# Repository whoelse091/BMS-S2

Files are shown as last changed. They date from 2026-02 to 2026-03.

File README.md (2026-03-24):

# BMS-USB CHARGE 2S (Rev V1)
 
Плата управления и защиты (BMS) для сборок из двух последовательных Li-Ion аккумуляторов (2S). Рассчитана на длительную работу при токах до 7 А с пиковой нагрузкой до 10 А и пассивной балансировкой ячеек



---
 
## Характеристики
 
| Параметр | Значение |
| :--- | :--- |
| Конфигурация | 2S (7.4–8.4 В) |
| Номинальный ток нагрузки | 7 А |
| Пиковый ток | 10 А |
| Ток балансировки | 100 мА |
| Контроллер защиты | HY2120 |
| Контроллер балансировки | HY2213 |
 
---

## Схемотехника
 
Схема состоит из трёх функциональных блоков: защита сборки, балансировка ячейки 1 и балансировка ячейки 2. Аккумуляторы BT1 и BT2 соединены последовательно: PB+ → BT1 → B1+2 (средняя точка) → BT2 → GND.

 

### Защита сборки (Battery Protection)
 
Контроллер **U3 (HY2120)** отслеживает напряжение каждой ячейки и ток нагрузки, обеспечивая защиту от перезаряда, переразряда и короткого замыкания.



Входные цепи:
- Напряжение верхней ячейки (BT1) снимается между PB+ и B1+2 через резистивные цепи R2 (330 Ом) на вход VDD и RB (330 Ом) на вход VC.
- Конденсаторы C3 и C5 (по 0.1 мкФ) — блокировочные ёмкости по питанию и опорному входу.
 
Токовый датчик:
- Вход CS (pin 3) подключён через R9 (2 кОм) к средней точке между стоковыми выводами силовых MOSFET. Падение напряжения на открытых каналах Q3/Q4 используется как шунт для определения тока нагрузки.
 
Силовые ключи:
- **Q3** и **Q4** (AOD4184A) включены по схеме back-to-back (общий сток) в минусовую шину между GND сборки и GND1 нагрузки.
- Выход **OD** (pin 1) управляет затвором Q4 и отвечает за отключение при переразряде.
- Выход **OC** (pin 2) управляет затвором Q3 и отвечает за отключение при перезаряде/КЗ.
- R14 и R15 (по 100 кОм) — подтяжка затворов к GND для гарантированного закрытия MOSFET при обесточенном контроллере.
 
### Балансировка ячейки 1 (Balancing Battery 1)
 
Контроллер **U1 (HY2213)** контролирует напряжение на BT1 через входы VDD(B1) и VSS. Питание подведено через R1 (100 Ом) с блокировочным конденсатором C1 (0.1 мкФ).
 
При достижении порогового напряжения на ячейке (типовое ~4.25 В) выход **OUT1** (pin 6) через R16 (100 кОм) открывает MOSFET **Q1 (AOD4184A)**, который подключает балансировочную нагрузку — параллельную пару резисторов **R4 и R6** (по 90 Ом, суммарно 45 Ом). Ток балансировки при напряжении ячейки ~4.2 В составляет примерно **93 мА**.



### Балансировка ячейки 2 (Balancing Battery 2)
 
Схема полностью симметрична блоку балансировки ячейки 1.
 
Контроллер **U2 (HY2213)** контролирует напряжение на BT2. Питание — через R5 (100 Ом), блокировка — C4 (0.1 мкФ). Выход **OUT2** (pin 6) через R17 (100 кОм) управляет MOSFET **Q2 (AOD4184A)**, который коммутирует балансировочные резисторы **R3 и R7** (по 90 Ом, суммарно 45 Ом).
 
### Выходной разъём (Wire-Pad)
 
Выходные контакты:
- **J2** (Conn_01x01) — PB+ (положительный выход сборки).
- **J3** (Conn_01x01) — GND1 (отрицательный выход, после силовых ключей защиты).
 
---

## Конструктив платы
 
Двухслойная PCB, спроектированная под высокие токовые нагрузки.
 
- **Силовые трассы** — увеличенная ширина дорожек для минимизации падения напряжения и нагрева при пиковых 10 А.
- **Заливка медью (Copper Pour)** — сплошные полигоны GND на обоих слоях. Обеспечивают низкоимпедансную «землю» и улучшают помехоустойчивость аналоговых цепей HY2120/HY2213.
- **Монтаж аккумуляторов** — контактные площадки и крепления вынесены на нижний слой (Bottom), что разделяет силовую и сигнальную части.
- **Теплоотвод** — via stitching под силовыми компонентами и широкие медные полигоны для рассеивания тепла от балансировочных резисторов и MOSFET.
- **Форм-фактор** — компактный, рассчитан на прямую установку поверх аккумуляторной сборки.




## Структура проекта
* `/electronics` — Схемы (PDF) и исходники KiCad.
* `/gerber` — Файлы для производства печатных плат.
* `/docs` — Инструкции и фотографии тестов.

## Особенность первого запуска и выхода из защиты
 
После сборки платы или после срабатывания защиты (переразряд, КЗ) на выходе может отсутствовать напряжение — это **штатное поведение**, а не неисправность.
 
HY2120 при первом включении или после срабатывания защиты удерживает силовые MOSFET в закрытом состоянии. Для активации необходимо выполнить одно из действий:
 
1. **Подать зарядное напряжение** на выход платы (PB+ и GND1). Контроллер определит наличие зарядного тока и откроет ключи.
2. **Кратковременно замкнуть вход CS на VCC.** Это принудительно сбрасывает состояние защиты и переводит контроллер в рабочий режим.
 
После успешной активации плата будет работать в нормальном режиме до следующего срабатывания защиты.

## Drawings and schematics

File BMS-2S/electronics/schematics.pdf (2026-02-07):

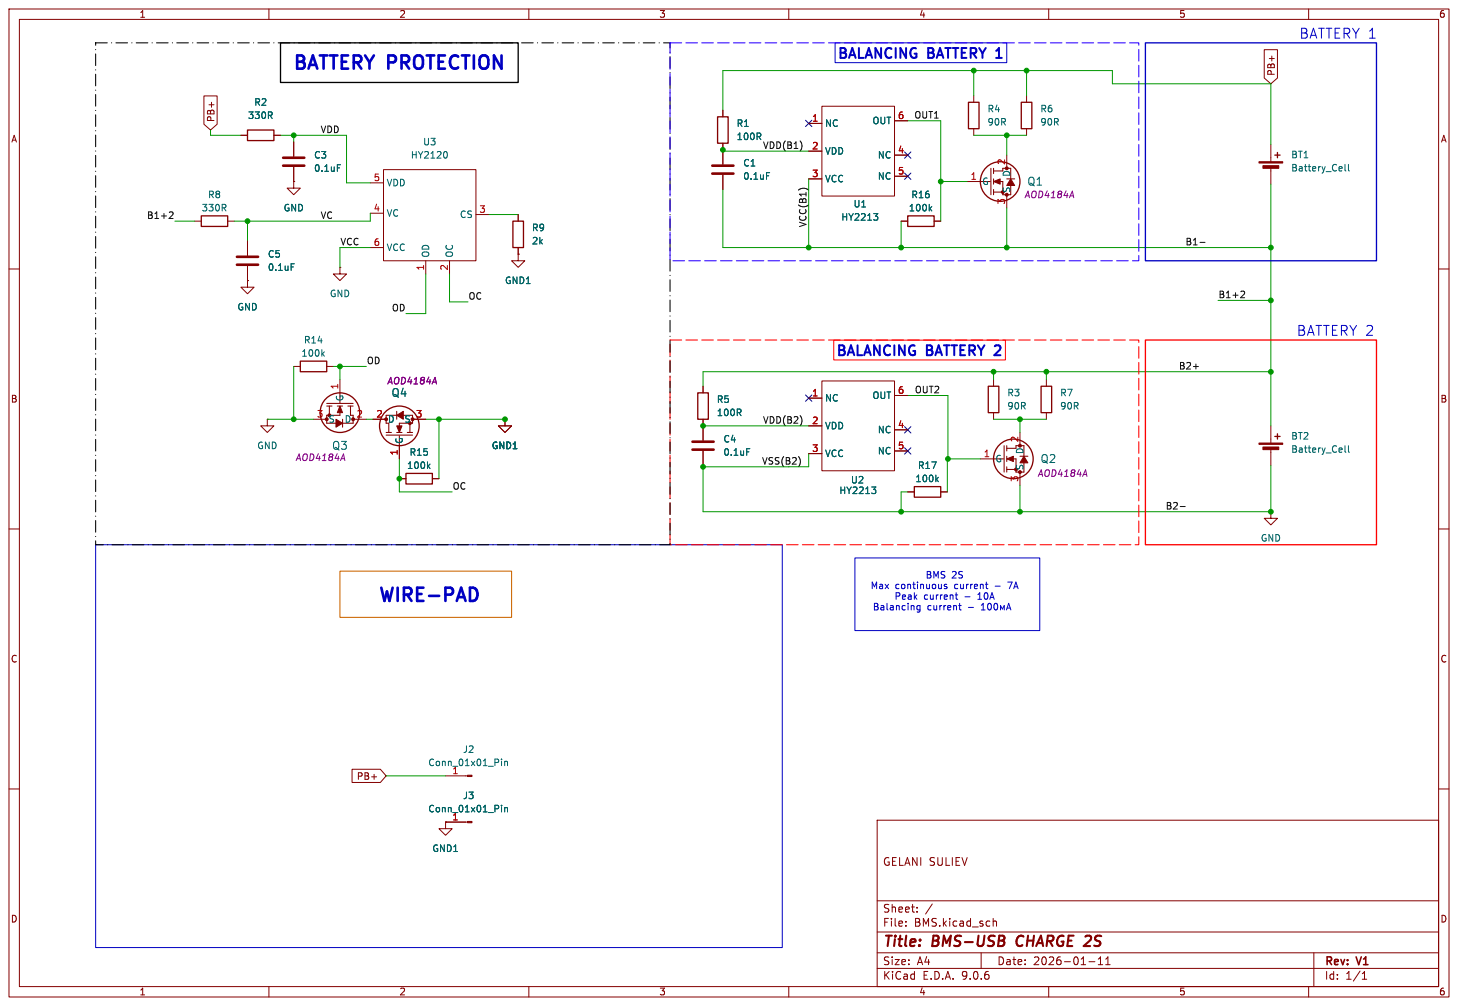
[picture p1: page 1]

Id: 1/1 Title: BMS-USB CHARGE 2S

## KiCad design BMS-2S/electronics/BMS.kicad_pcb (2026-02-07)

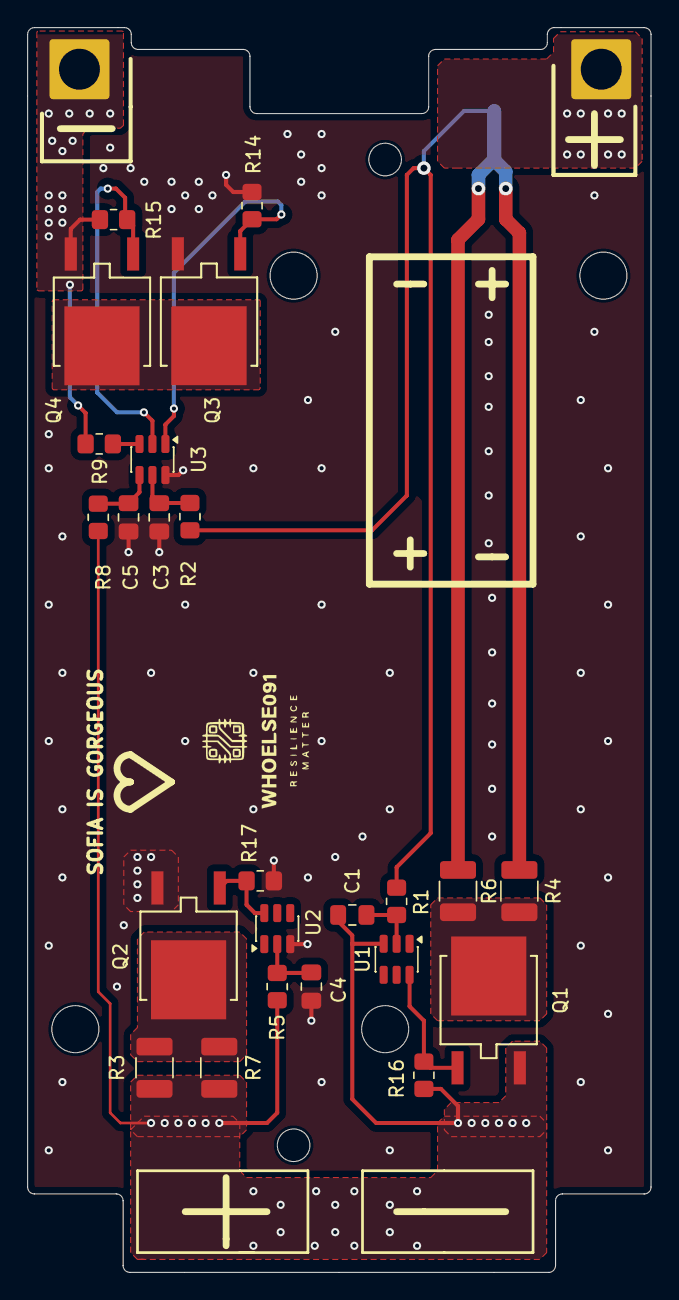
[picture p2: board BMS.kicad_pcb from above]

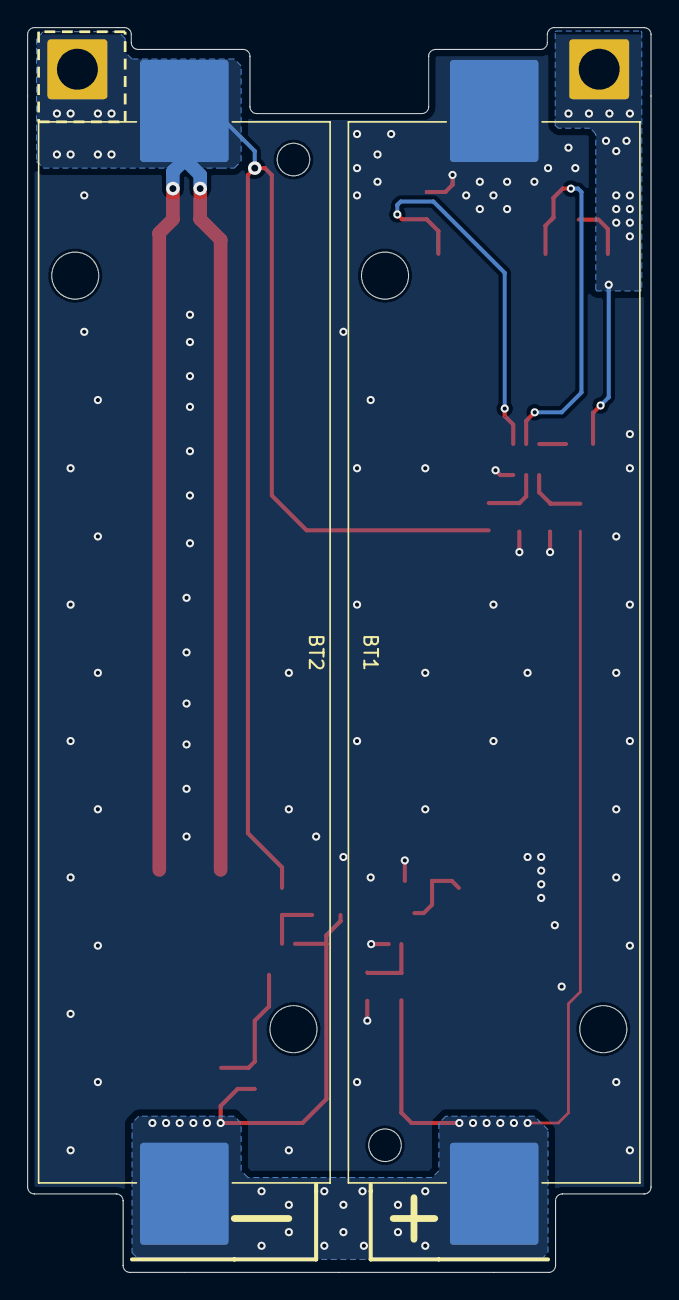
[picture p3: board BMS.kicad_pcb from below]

Board: 2 copper layers, 45.7 x 91.2 mm, 28 parts (2 on the bottom side), 16 nets.

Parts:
+: Conn_01x01_Pin; SolderWire-2.5sqmm_1x01_D2.4mm_OD4.4mm
-: Conn_01x01_Pin; SolderWire-2.5sqmm_1x01_D2.4mm_OD4.4mm
BT1, BT2: Battery_Cell; BatteryHolder_Keystone_1042_1x18650
C1, C3, C4, C5: 0.1uF; C_0805_2012Metric_Pad1.18x1.45mm_HandSolder
Q1, Q2, Q3, Q4: AOD4184A; TO252_AOS-L
R1, R5: 100R; R_0805_2012Metric_Pad1.20x1.40mm_HandSolder
R2, R8: 330R; R_0805_2012Metric_Pad1.20x1.40mm_HandSolder
R3, R4, R6, R7: 90R; R_1210_3225Metric_Pad1.30x2.65mm_HandSolder
R9: 2k; R_0805_2012Metric_Pad1.20x1.40mm_HandSolder
R14, R15, R16, R17: 100k; R_0805_2012Metric_Pad1.20x1.40mm_HandSolder
U1, U2: HY2213; SOT-23-6
U3: HY2120; SOT-23-6

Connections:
/B1+2: BT1.2 (-), BT2.1 (+), C1.2, Q1.3 (S), R3.1, R5.1, R7.1, R8.1, R16.1, U1.3 (VCC)
/OC: Q4.1 (G), R15.1, U3.2 (OC)
/OD: Q3.1 (G), R14.2, U3.1 (OD)
/OUT1: Q1.1 (G), R16.2, U1.6 (OUT)
/OUT2: Q2.1 (G), R17.2, U2.6 (OUT)
/VC: C5.1, R8.2, U3.4 (VC)
/VDD: C3.1, R2.2, U3.5 (VDD)
/VDD(B1): C1.1, R1.2, U1.2 (VDD)
/VDD(B2): C4.1, R5.2, U2.2 (VDD)
GND: BT2.2 (-), C3.2, C4.2, C5.2, Q2.3 (S), Q3.3 (S), R14.1, R17.1, U2.3 (VCC), U3.6 (VCC)
GND1: -.1, Q4.3 (S), R9.1, R15.2
unnamed: Q1.2 (D), R4.2, R6.2
unnamed: Q2.2 (D), R3.2, R7.2
unnamed: Q3.2 (D), Q4.2 (D)
unnamed: R9.2, U3.3 (CS)
PB+: +.1, BT1.1 (+), R1.1, R2.1, R4.1, R6.1

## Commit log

2026-02-07 Update README with images and specifications
    Добавлены изображения и технические характеристики для BMS.
2026-02-07 Enhance README with PCB design details
    Added detailed PCB design information including layers, trace width, copper pour, battery mounting, heat dissipation, and dimensions.
2026-03-24 Revise README with specifications and operational details
    Updated the README.md to include detailed specifications, features, and operational notes for the BMS-USB CHARGE 2S (Rev V1) board.
